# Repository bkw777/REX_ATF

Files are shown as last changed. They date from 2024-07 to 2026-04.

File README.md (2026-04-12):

# NOT WORKING

If you just want a REX, buy a [REX#](https://bitchin100.com/wiki/index.php?title=REXsharp) or build a [REX Classic](https://github.com/bkw777/REX_Classic).

This is is an attempt to port REX Classic to a different CPLD chip.  
REX Classic is built around the Xilinx XCR3064XL, which is discontinued.  
ATF1504ASL is a similar part that is still available.  
Do not bother trying to build this yet unless you actually want to help GET it working.  
Because it DOES NOT WORK yet. But it seems to be close...  

## Current Status

Can't figure out a way to replicate the Xilinx internal pullup feature while using the Quartus -> EPM7064S -> POF2JED workflow, so at least for now we have external pullup resistors on the CSA & CSB pins (formerly TP1 & TP2). All other pins should be ok since they are connected to the bus.

Quartus 13.0 compiles the VHDL and creates `rexbrd.pof`.  
`pof2jed` creates `rexbrd.jed`.  
`atmisp` creates `rexbrd.svf`.  
`openocd` programs `rexbrd.svf` to the device.  

The machine still runs normally with the REX installed, so at least the REX is not waking up and interfering with the bus when not selected.

`rf149.co` runs without error.  
The "wiping blocks" stage goes way too fast.  
`CALL 63012` hangs.

TODO: observe the bus with https://github.com/bkw777/Molex_7880x_bus_tap

----
# REX_ATF

[REX Classic](http://tandy.wiki/REX) built on Microchip ATF1504 instead of Xilinx XCR3064

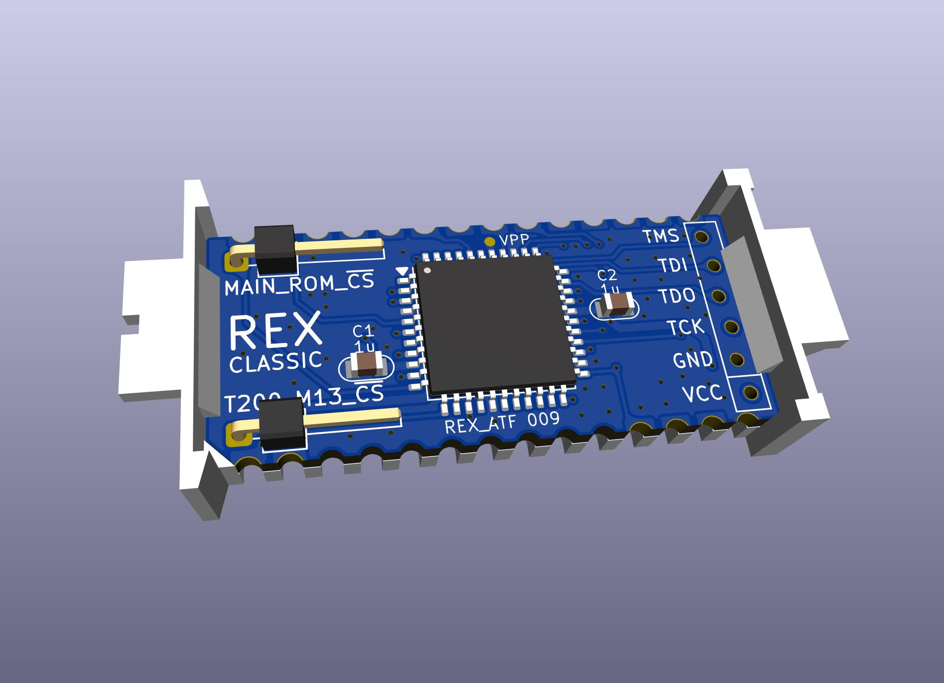
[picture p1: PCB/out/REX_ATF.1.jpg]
  
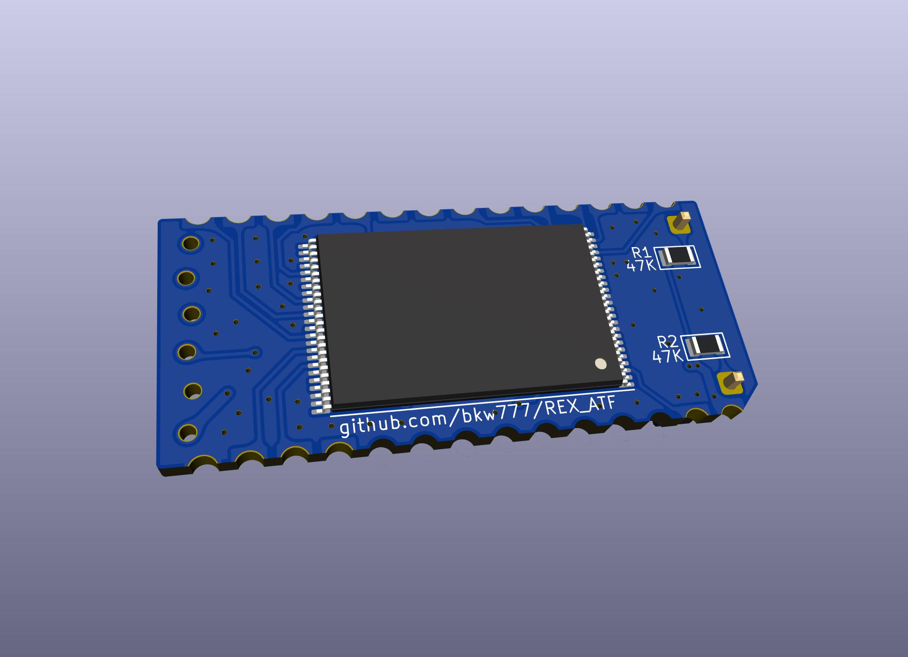
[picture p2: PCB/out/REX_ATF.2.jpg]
  
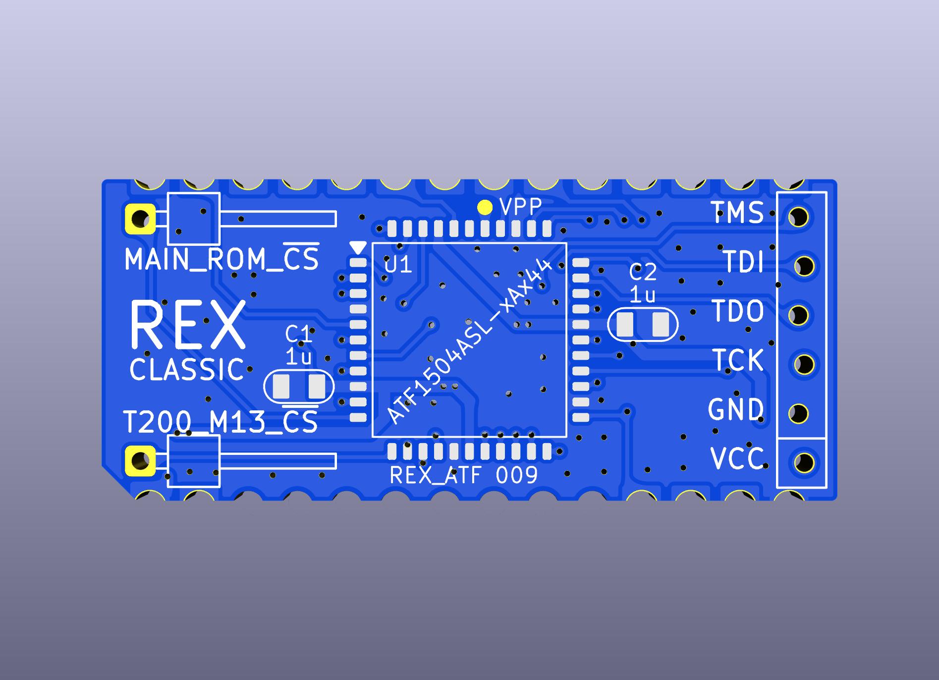
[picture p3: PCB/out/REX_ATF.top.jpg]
  
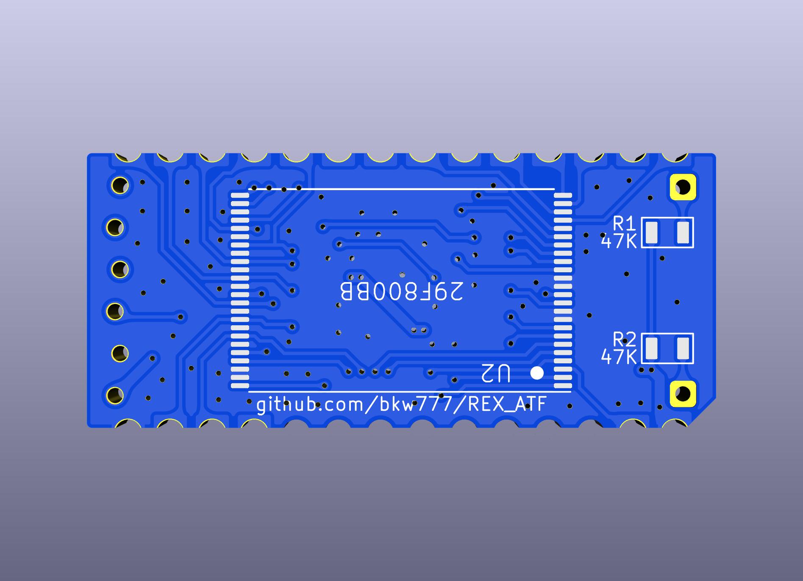
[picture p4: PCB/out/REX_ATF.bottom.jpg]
  
  

# What is it?

REX Classic is an on-board software-controlled rom library for TRS-80 Model 100, 102, or 200.

REX was originally designed around a Xilinx XCR3064XL CPLD, but Xilinx has stopped producing those.

This is a version of REX Classic using the same VHDL code, but compiled for a Microchip ATF1504ASL CPLD, which is still an active part.

# BOM

1 x ATF1504ASL TQFP44 - CPLD 64MC 5V  
https://www.digikey.com/en/products/detail/microchip-technology/ATF1504ASL-25AU44/1008353

1 x 29F800BB TSOP48 ex: AM29F800BB, M29F800FB, MX29F800CB - 8Mx8/4Mx16 FLASH parallel 5V bottom-boot  
https://www.digikey.com/en/products/detail/alliance-memory-inc/M29F800FB5AN6F2/12180108

2 x 1uF MLCC 0805 16V+  
https://www.digikey.com/en/products/detail/yageo/CC0805KKX7R7BB105/2103103

Gerbers & CPLD bitstream in [releases](../../releases/latest). (not working yet, so no release yet)

Carrier: https://shop.jawstec.com/3d-printed-molex-78802-pcb-carrier_p641.php?id=641  
(https://github.com/bkw777/Molex78802_Module/blob/master/Carrier/Molex78802_PCB_28.stl)

# Programming the CPLD
Install [openocd](https://openocd.org/) and a wrapper script [atfsvf](https://github.com/bkw777/ATF150x_uDEV/blob/main/bin/atfsvf):  
```
$ sudo apt install openocd
$ wget https://github.com/bkw777/ATF150x_uDEV/raw/main/bin/atfsvf
$ install -m 755 atfsvf ~/.local/bin/
```

Programmer hardware:  
 * [FT232R or FT232H usb-ttl module that can supply 5V VCC](https://github.com/bkw777/ATF150x_uDEV/blob/main/programming.md#hardware)
 * 6-pin length of generic 2.54mm single row square male pin header
 * 6 female dupont wires
 * [connection pinout table](https://github.com/bkw777/ATF150x_uDEV/blob/main/programming.md#hardware)

Example using an [FT232R usbc-ttl-serial module](https://amazon.com/dp/B0CQVB6JFV)  
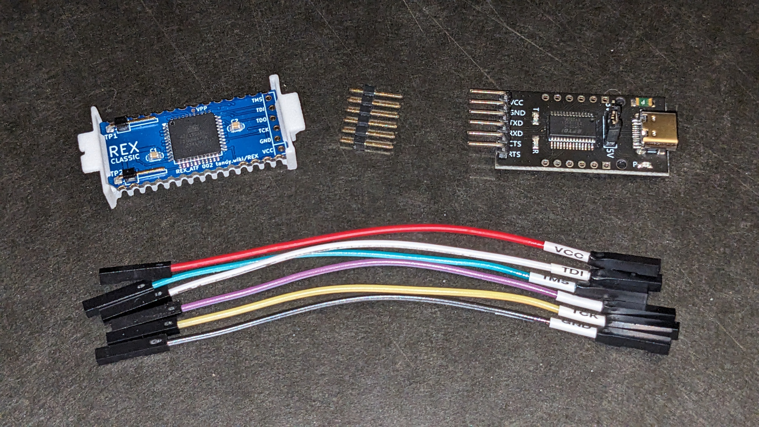
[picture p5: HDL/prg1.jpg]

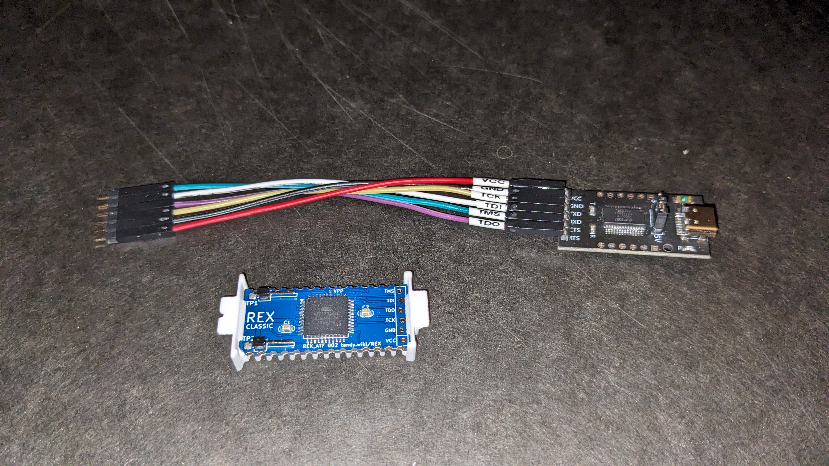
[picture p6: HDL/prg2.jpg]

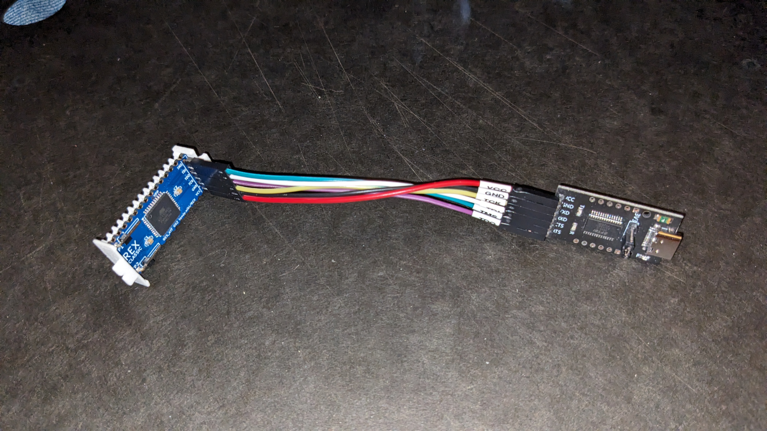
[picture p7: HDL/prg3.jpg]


Get the SVF file from [Releases](../../releases/latest). (No releases yet since it doesn't work yet)

Use the atfsvf script to program the chip with the svf.  
If you have a FT232H module instead of FT232R, then change ft232r to ft232h below.  
`$ atfsvf ft232r ATF1504ASL rexbrd.svf`

# Usage
Use the normal [REX Classic](http://bitchin100.com/wiki/index.php?title=REXclassic) software and documentation.

Example on linux:

## install [dl2](https://github.com/bkw777/dl2)
```
$ git clone https://github.com/bkw777/dl2.git
$ cd dl2 && make clean all && sudo make install
```

## connect 100 to pc by serial
reference: http://tandy.wiki/Model_T_Serial_Cable  
https://www.pccables.com/products/00103.html  
https://www.amazon.com/gp/product/B074VN9ZG4/  

## load the REX firmware
```
$ wget https://www.bitchin100.com/wiki/images/3/38/R49_M100T102_260_rebuild.zip
$ unzip R49_M100T102_260_rebuild.zip
$ co2ba rf149.co call >rf149.do
$ dl -vb rf149.do && dl -vu
```
(follow the on-screen directions in the terminal and on the 100)  
Then SHIFT+BREAK+RESET on the 100  
Then Power-cycle the 100  

## Try to activate the REX
In BASIC: `CALL 63012`  
(currently hangs)

# Generating the SVF from the VHDL source
HDL/Compile_HDL.md

# Credits
Original REX design is by Steven Adolph  
http://bitchin100.com/wiki/index.php?title=REX  
http://www.club100.org/memfiles/index.php?direction=0&order=&directory=Steve%20Adolph

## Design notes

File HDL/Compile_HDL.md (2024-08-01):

# How to generate the .svf from the VHDL source

## Install Quartus 13.0  
You can omit ModelSim and all device families except MAX7000 if you want a smaller install.  
Directions for Ubuntu 23.10: https://gist.github.com/bkw777/a6a2888f482802f2e520165858268cd3

## Install ATMISP, 5vcomp, openocd, and some wrapper scripts
https://github.com/bkw777/ATF150x_uDEV/blob/main/programming.md  
Basically do the entire "Here is a start to finish install on Ubuntu 23.10"  
You don't need wincupl for this project, but you do need everything else.  

## Install POF2JED
You also need POF2JED which is not mentioned above because that document only covers the WINCUPL workflow, but you get pof2jed from the same place as atmisp and wincupl, and install the same way in the same wine environment:
```
$ wget http://ww1.microchip.com/downloads/archive/pof2jed.zip
$ unzip pof2jed.zip
$ wine_atmel WinPof2jed45.exe
$ cat >~/.local/bin/pof2jed <<%EOF
#!/bin/sh
# Wrapper to run POF2JED
# Install in ~/.local/bin along with wine_atmel

exec wine_atmel c:/pof2jed/bin/pof2jed.exe "\$@"
%EOF
$ chmod 755 ~/.local/bin/pof2jed
$ cat >~/.local/bin/winpof2jed <<%EOF 
#!/bin/sh
# Wrapper to run WinPOF2JED
# Install in ~/.local/bin along with wine_atmel

# "start" makes the help buttons work
exec wine_atmel start c:/pof2jed/bin/winpof2jed.exe "\$@"
%EOF
$ chmod 755 ~/.local/bin/winpof2jed
```

## Compile the VDHL to POF
```
$ cd .../HDL/rexbrd
$ q13 rexbrd
```

Press the "play" button to generate `output_files/rexbrd.pof`  
(or Processing -> Start Compilation)

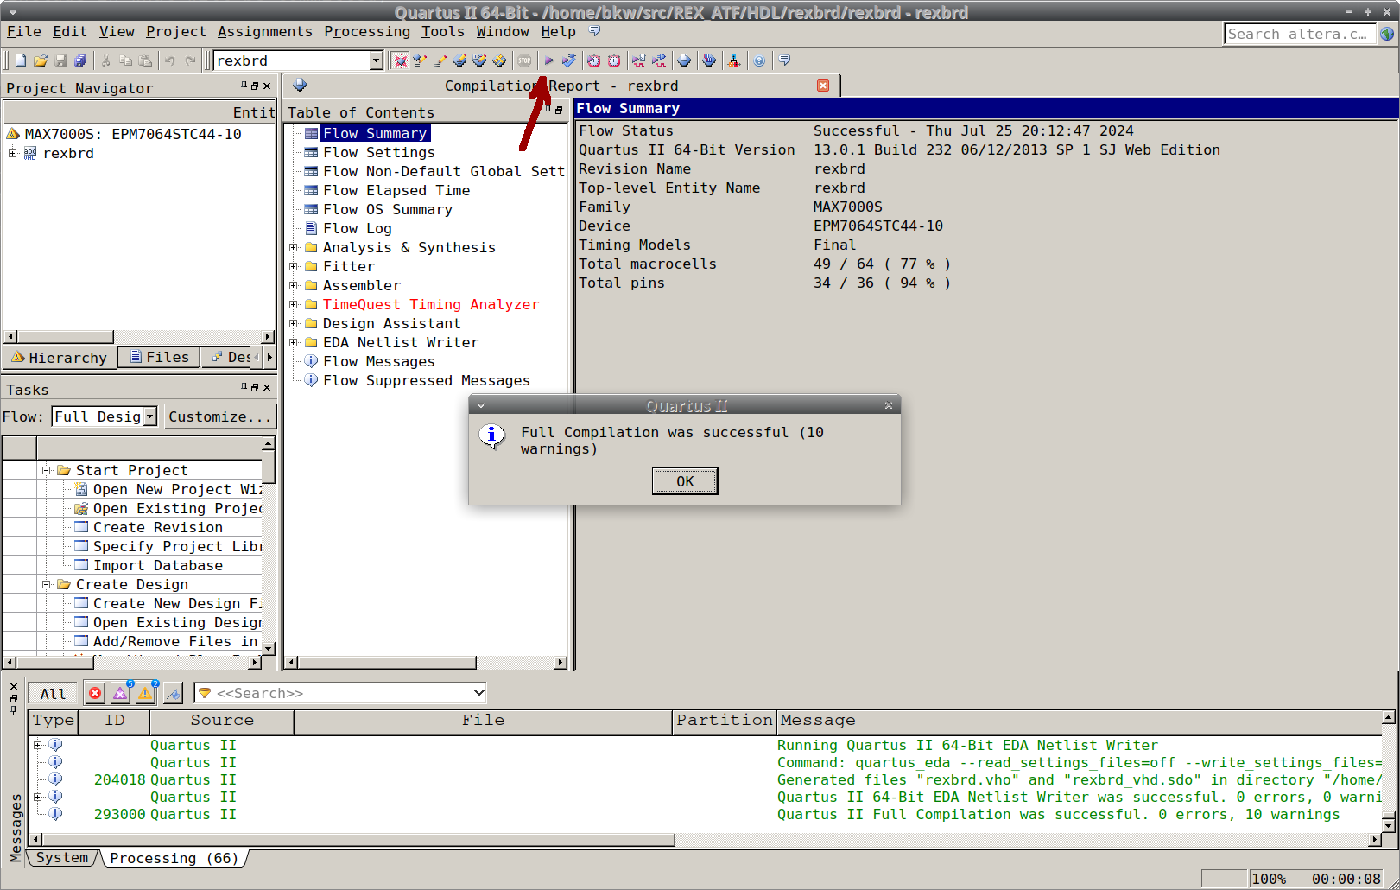
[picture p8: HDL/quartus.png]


This produces a `*.pof` which could be used to program an EPM7064S from within Quartus,  
if we were actually using an EPM7064S.

## Convert POF for EPM7064S to JED for ATF1504AS
[pof2jed.txt](pof2jed.txt)  
```
$ cd output_files
$ pof2jed rexbrd -verbose -device 1504as -pinclk -pin_keep -MC_power on -power_reset -GCLK3_ITD -JTAG on -TDI_PULLUP -TMS_PULLUP
```
Ignore the warning message about the JTAG pins.

This produces a `*.jed` which could be used by ATMISP to program a ATF1504ASL if you had an ATDH1150USB programmer.

## Convert JED to SVF
ATMISP can not program the JED to the chip with any other kind of programmer except ATDH1150USB ($90+), but it can read the JED and write out a SVF file.  
https://github.com/bkw777/ATF150x_uDEV/blob/main/programming.md#convert-the-jed-to-svf

The `.chn` file pre-loads most settings,  
but you still need to manually select `[x] Write SVF file`,  
and enter `rexbrd.svf` under `SVF File Name`.  

`$ atmisp rexbrd.chn`

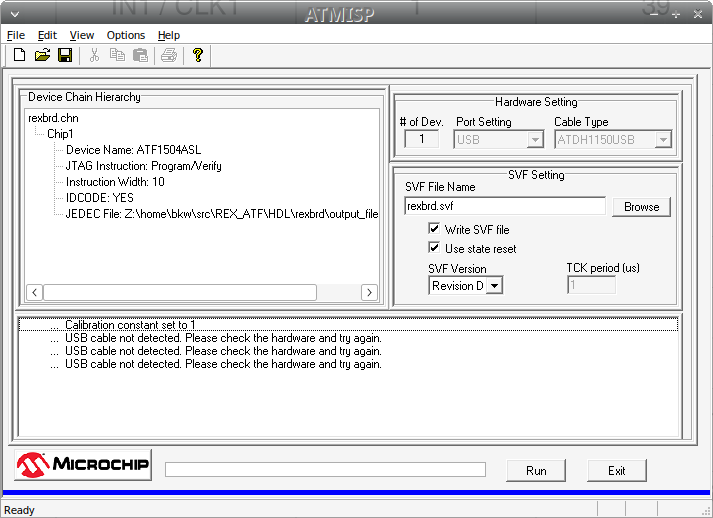
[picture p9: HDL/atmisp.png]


This produces a `*.svf` which any generic jtag software and hardware can use to program the chip.

# How to flash the .svf to the device

## Setup JTAG programmer hardware
https://github.com/bkw777/ATF150x_uDEV/blob/main/programming.md#hardware)  
To make the physical JTAG connection, you only need 6 female-female dupont wires and a 6-pin length of common 2.54mm single-row square pin header.  
In these pics, the usbc module has a FT232R chip, so the pinout follows the FT232R table in the programming doc above.  
TX-TCK  
RX-TDI  
CTS-TMS  
RTS-TDO  




## Program the SVF to the device
https://github.com/bkw777/ATF150x_uDEV/blob/main/programming.md#program-the-device-with-the-svf  

`$ atfsvf ft232r ATF1504ASL rexbrd.svf`

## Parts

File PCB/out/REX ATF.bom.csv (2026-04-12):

Reference | Value | Datasheet | Footprint | Qty | DNP | MPN | Description
C1,C2 | 1u | datasheets/CL21B105KAFNNNE.pdf | 000_LOCAL:C_0805 | 2 |  | CL21B105KAFNNNE | 1 µF ±10% 25V Ceramic Capacitor X7R 0805
R1,R2 | 47K | datasheets/PYU-RC_GROUP_51_ROHS_L.pdf | 000_LOCAL:R_0805 | 2 |  | RC0805JR-0747KL | R 47k 0805
U1 | ATF1504ASL-xAx44 | datasheets/ATF1504AS.pdf | 000_LOCAL:VQFP44 | 1 |  | ATF1504ASL-25AU44 | ATMEL Altera Microchip 64-Macrocell CPLD, VQFP-44
U2 | 29F800BB | datasheets/M29F800.pdf | 000_LOCAL:TSOP-48 | 1 |  | M29F800FB5AN6F2 | FLASH - NOR Memory IC 1Mx8 512Kx16 Parallel 5v 48-TSOP

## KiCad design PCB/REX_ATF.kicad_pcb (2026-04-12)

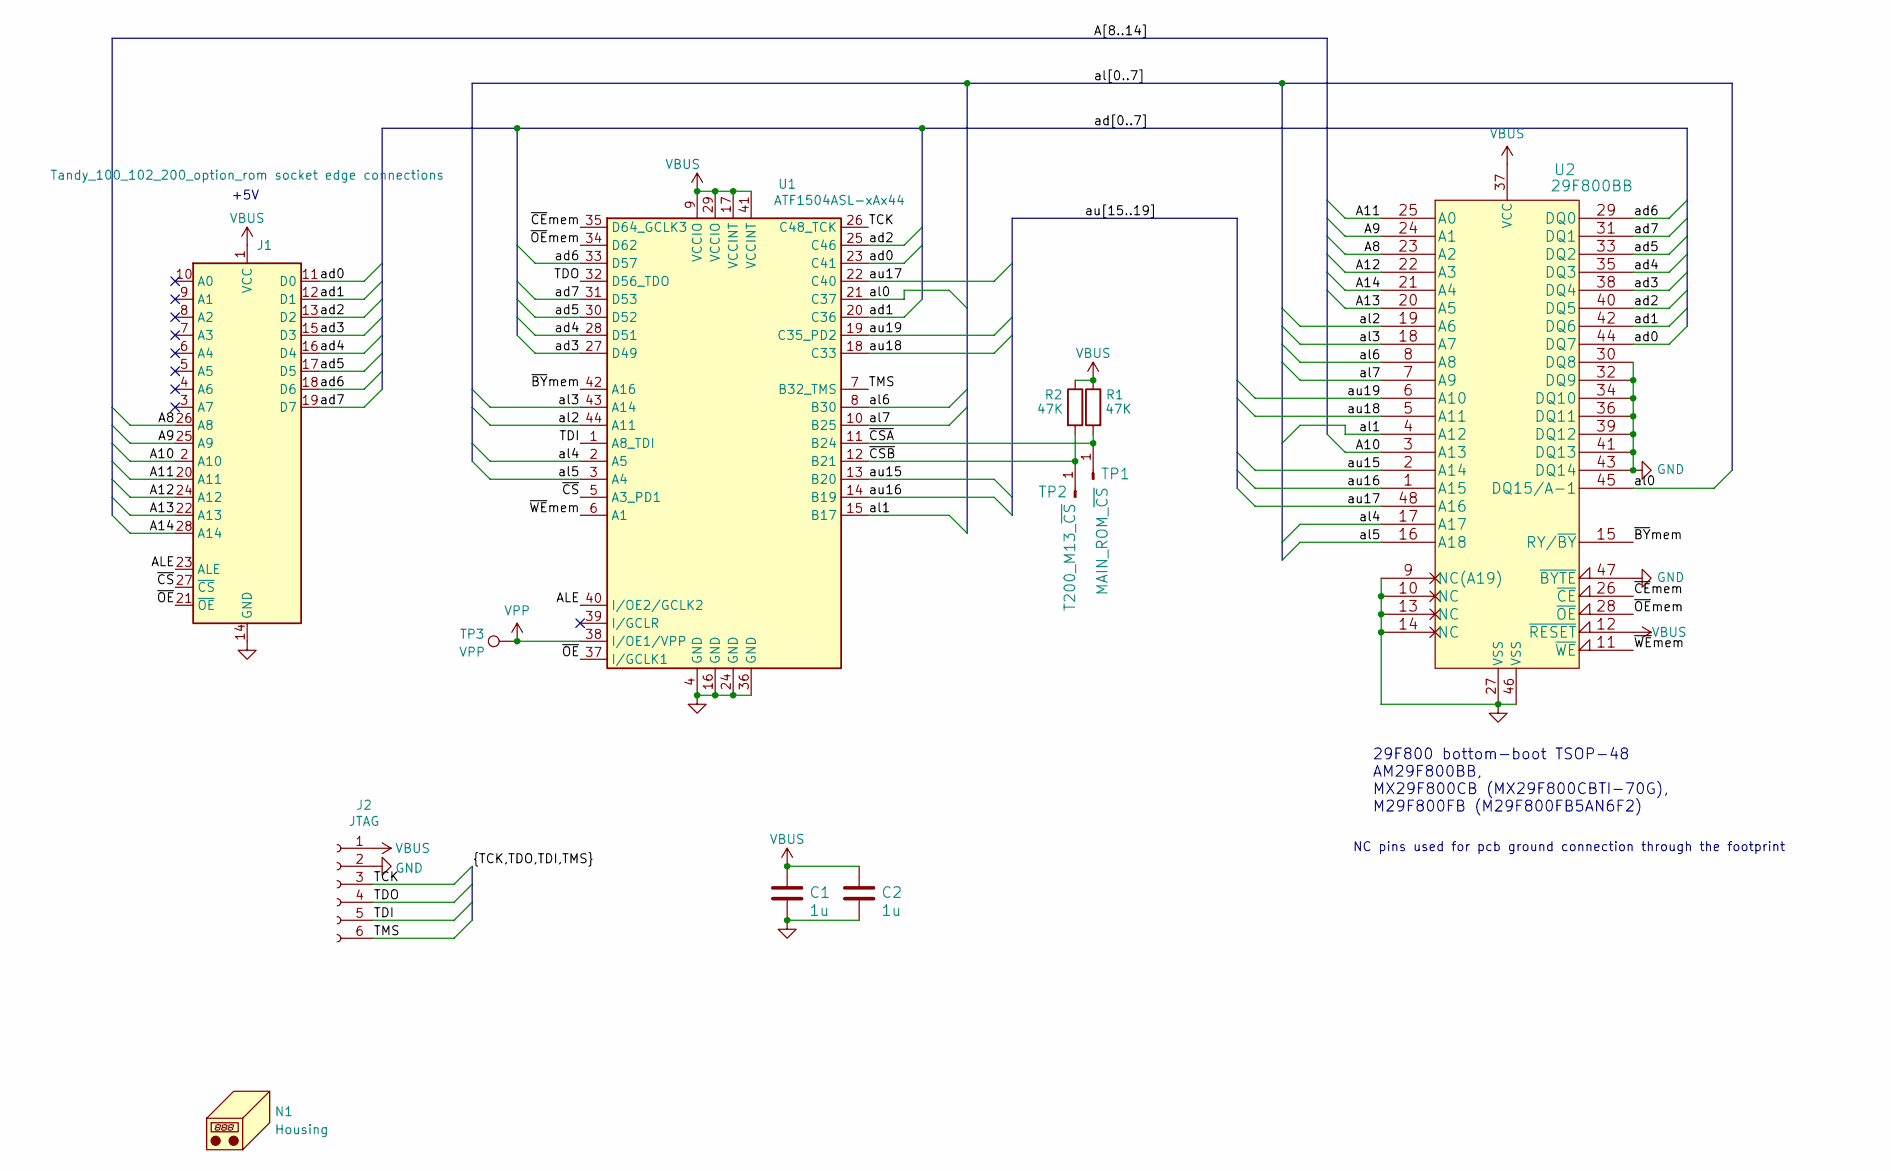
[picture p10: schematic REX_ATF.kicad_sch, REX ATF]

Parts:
C1, C2: 1u; C_0805; MPN CL21B105KAFNNNE
J1: Tandy_100_102_200_option_rom socket edge connecti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; Molex78802_PCB_28_REX
J2: JTAG; 1x6_pcb_socket
N1: Housing; Housing_Molex78802_PCB_28
R1, R2: 47K; R_0805; MPN RC0805JR-0747KL
TP1: MAIN_ROM_~{CS}; 1x1_pin_h
TP2: T200_M13_~{CS}; 1x1_pin_h
TP3: VPP; TP_D0.8
U1: ATF1504ASL-xAx44; VQFP44; MPN ATF1504ASL-25AU44
U2: 29F800BB; TSOP-48; MPN M29F800FB5AN6F2

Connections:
/A8: J1.26 (A8), U2.23 (A2)
/A9: J1.25 (A9), U2.24 (A1)
/A10: J1.2 (A10), U2.3 (A13)
/A11: J1.20 (A11), U2.25 (A0)
/A12: J1.24 (A12), U2.22 (A3)
/A13: J1.22 (A13), U2.20 (A5)
/A14: J1.28 (A14), U2.21 (A4)
/ALE: J1.23 (ALE), U1.40 (I/OE2/GCLK2)
/TCK: J2.3, U1.26 (C48_TCK)
/TDI: J2.5, U1.1 (A8_TDI)
/TDO: J2.4, U1.32 (D56_TDO)
/TMS: J2.6, U1.7 (B32_TMS)
/ad0: J1.11 (D0), U1.23 (C41), U2.44 (DQ7)
/ad1: J1.12 (D1), U1.20 (C36), U2.42 (DQ6)
/ad2: J1.13 (D2), U1.25 (C46), U2.40 (DQ5)
/ad3: J1.15 (D3), U1.27 (D49), U2.38 (DQ4)
/ad4: J1.16 (D4), U1.28 (D51), U2.35 (DQ3)
/ad5: J1.17 (D5), U1.30 (D52), U2.33 (DQ2)
/ad6: J1.18 (D6), U1.33 (D57), U2.29 (DQ0)
/ad7: J1.19 (D7), U1.31 (D53), U2.31 (DQ1)
/al0: U1.21 (C37), U2.45 (DQ15/A-1)
/al1: U1.15 (B17), U2.4 (A12)
/al2: U1.44 (A11), U2.19 (A6)
/al3: U1.43 (A14), U2.18 (A7)
/al4: U1.2 (A5), U2.17 (A17)
/al5: U1.3 (A4), U2.16 (A18)
/al6: U1.8 (B30), U2.8 (A8)
/al7: U1.10 (B25), U2.7 (A9)
/au15: U1.13 (B20), U2.2 (A14)
/au16: U1.14 (B19), U2.1 (A15)
/au17: U1.22 (C40), U2.48 (A16)
/au18: U1.18 (C33), U2.5 (A11)
/au19: U1.19 (C35_PD2), U2.6 (A10)
/~BYmem: U1.42 (A16), U2.15 (RY/~BY)
/~CEmem: U1.35 (D64_GCLK3), U2.26 (~CE)
/~CSA: R1.2, TP1.1, U1.11 (B24)
/~CSB: R2.2, TP2.1, U1.12 (B21)
/~CS: J1.27 (~CS), U1.5 (A3_PD1)
/~OE: J1.21 (~OE), U1.37 (I/GCLK1)
/~OEmem: U1.34 (D62), U2.28 (~OE)
/~WEmem: U1.6 (A1), U2.11 (~WE)
GND: C1.2, C2.2, J1.14 (GND), J2.2, U1.4 (GND), U1.16 (GND), U1.24 (GND), U1.36 (GND), U2.9 (NC(A19)), U2.10 (NC), U2.13 (NC), U2.14 (NC), U2.27 (VSS), U2.30 (DQ8), U2.32 (DQ9), U2.34 (DQ10), U2.36 (DQ11), U2.39 (DQ12), U2.41 (DQ13), U2.43 (DQ14), U2.46 (VSS), U2.47 (~BYTE)
VBUS: C1.1, C2.1, J1.1 (VCC), J2.1, R1.1, R2.1, U1.9 (VCCIO), U1.17 (VCCINT), U1.29 (VCCIO), U1.41 (VCCINT), U2.12 (~RESET), U2.37 (VCC)
VPP: TP3.1, U1.38 (I/OE1/VPP)

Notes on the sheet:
+5V
29F800 bottom-boot TSOP-48 AM29F800BB, MX29F800CB (MX29F800CBTI-70G), M29F800FB (M29F800FB5AN6F2)
NC pins used for pcb ground connection through the footprint

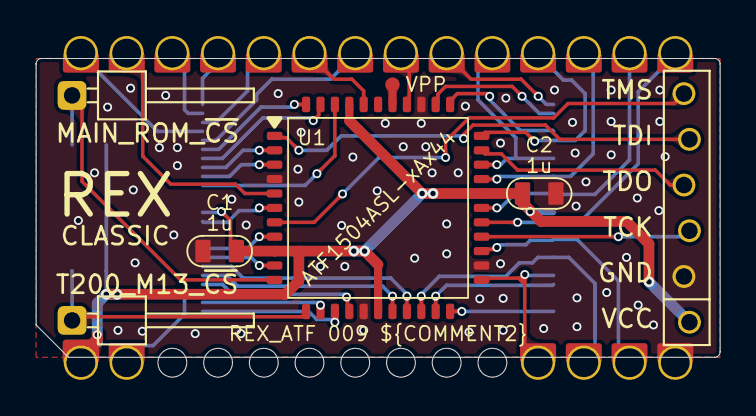
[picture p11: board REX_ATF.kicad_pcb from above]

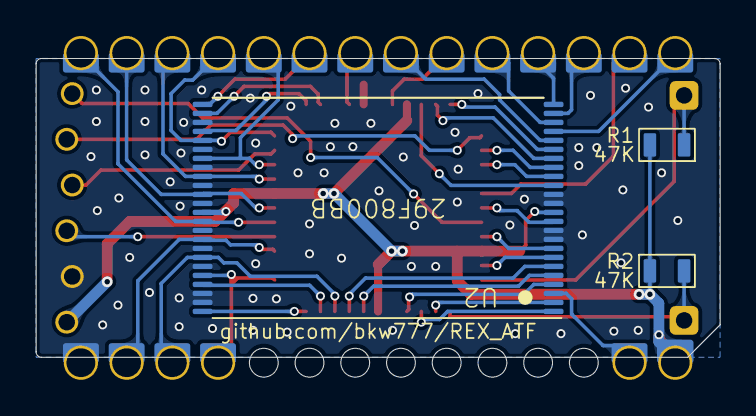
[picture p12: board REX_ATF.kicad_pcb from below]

Board: 2 copper layers, 38.0 x 16.6 mm, 12 parts (3 on the bottom side), 44 nets.

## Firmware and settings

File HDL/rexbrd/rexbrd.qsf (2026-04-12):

# -------------------------------------------------------------------------- #
#
# Copyright (C) 1991-2013 Altera Corporation
# Your use of Altera Corporation's design tools, logic functions 
# and other software and tools, and its AMPP partner logic 
# functions, and any output files from any of the foregoing 
# (including device programming or simulation files), and any 
# associated documentation or information are expressly subject 
# to the terms and conditions of the Altera Program License 
# Subscription Agreement, Altera MegaCore Function License 
# Agreement, or other applicable license agreement, including, 
# without limitation, that your use is for the sole purpose of 
# programming logic devices manufactured by Altera and sold by 
# Altera or its authorized distributors.  Please refer to the 
# applicable agreement for further details.
#
# -------------------------------------------------------------------------- #
#
# Quartus II 64-Bit
# Version 13.0.1 Build 232 06/12/2013 Service Pack 1 SJ Web Edition
# Date created = 17:39:42  July 08, 2024
#
# -------------------------------------------------------------------------- #
#
# Notes:
#
# 1) The default values for assignments are stored in the file:
#		rexbrd_assignment_defaults.qdf
#    If this file doesn't exist, see file:
#		assignment_defaults.qdf
#
# 2) Altera recommends that you do not modify this file. This
#    file is updated automatically by the Quartus II software
#    and any changes you make may be lost or overwritten.
#
# -------------------------------------------------------------------------- #


set_global_assignment -name FAMILY MAX7000S
set_global_assignment -name DEVICE "EPM7064STC44-10"
set_global_assignment -name TOP_LEVEL_ENTITY rexbrd
set_global_assignment -name ORIGINAL_QUARTUS_VERSION "13.0 SP1"
set_global_assignment -name PROJECT_CREATION_TIME_DATE "17:39:42  JULY 08, 2024"
set_global_assignment -name LAST_QUARTUS_VERSION "13.0 SP1"
set_global_assignment -name PROJECT_OUTPUT_DIRECTORY output_files
set_global_assignment -name DEVICE_FILTER_PACKAGE TQFP
set_global_assignment -name DEVICE_FILTER_PIN_COUNT 44
set_global_assignment -name ERROR_CHECK_FREQUENCY_DIVISOR "-1"
set_global_assignment -name EDA_SIMULATION_TOOL "ModelSim-Altera (VHDL)"
set_global_assignment -name EDA_OUTPUT_DATA_FORMAT VHDL -section_id eda_simulation
set_location_assignment PIN_30 -to ad[5]
set_location_assignment PIN_19 -to au[19]
set_location_assignment PIN_23 -to ad[0]
set_location_assignment PIN_2 -to al[4]
set_location_assignment PIN_13 -to au[15]
set_location_assignment PIN_28 -to ad[4]
set_location_assignment PIN_21 -to al[0]
set_location_assignment PIN_10 -to al[7]
set_location_assignment PIN_33 -to ad[6]
set_location_assignment PIN_18 -to au[18]
set_location_assignment PIN_3 -to al[5]
set_location_assignment PIN_14 -to au[16]
set_location_assignment PIN_20 -to ad[1]
set_location_assignment PIN_43 -to al[3]
set_location_assignment PIN_27 -to ad[3]
set_location_assignment PIN_15 -to al[1]
set_location_assignment PIN_8 -to al[6]
set_location_assignment PIN_31 -to ad[7]
set_location_assignment PIN_22 -to au[17]
set_location_assignment PIN_25 -to ad[2]
set_location_assignment PIN_44 -to al[2]
set_global_assignment -name MAX7000_DEVICE_IO_STANDARD TTL
set_global_assignment -name OPTIMIZE_HOLD_TIMING OFF
set_global_assignment -name OPTIMIZE_MULTI_CORNER_TIMING OFF
set_global_assignment -name FITTER_EFFORT "STANDARD FIT"
set_global_assignment -name USE_CONFIGURATION_DEVICE ON
set_global_assignment -name MAX7000_USE_CHECKSUM_AS_USERCODE ON
set_global_assignment -name VHDL_SHOW_LMF_MAPPING_MESSAGES OFF
set_global_assignment -name ENABLE_DRC_SETTINGS ON
set_location_assignment PIN_6 -to WEmem
set_location_assignment PIN_42 -to BYmem
set_location_assignment PIN_40 -to ALE
set_location_assignment PIN_34 -to OEmem
set_location_assignment PIN_12 -to CSB
set_location_assignment PIN_37 -to OE
set_location_assignment PIN_35 -to CEmem
set_location_assignment PIN_11 -to CSA

set_global_assignment -name VHDL_FILE regis.vhd
set_global_assignment -name VHDL_FILE regis_vector.vhd
set_global_assignment -name VHDL_FILE rexbrd.vhd

set_location_assignment PIN_5 -to CS
set_global_assignment -name RESERVE_ALL_UNUSED_PINS_NO_OUTPUT_GND "AS INPUT TRI-STATED"

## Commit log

2024-07-22 move some traces around
    [REX_ATF.kicad_pcb]
2024-07-23 use nc pins for pcb ground path
    [REX_ATF.kicad_pcb, REX_ATF.kicad_sch]
2024-07-24 move ALE to a GCLK pin and init /CSA & /CSB high
    [REX_ATF.kicad_pcb, REX_ATF.kicad_sch]
2024-07-25 external pullups on CSA CSB
    [REX_ATF.kicad_pcb, REX_ATF.kicad_sch]
2024-08-01 enable pin keeper option
    [REX_ATF.kicad_pcb, REX_ATF.kicad_sch]
2026-04-12 minor pcb touches, update readme
    [REX ATF.bom.csv, REX_ATF.kicad_pcb, REX_ATF.kicad_sch]
2026-04-12 update pinout in vhdl to match pcb
